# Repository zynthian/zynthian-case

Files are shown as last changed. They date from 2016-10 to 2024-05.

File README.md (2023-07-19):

# Zynthian Case

[Zynthian](http://zynthian.org) is an Open Synth Platform based in Raspberry Pi, Linux (Raspbian) and Free Software Synthesizers (mostly!).

Image of the official Zynthian Aluminium case

This repository contains the stuff related to case building: plots, schemes, renders, photos, CNC files, ...
You can find useful information about [building a Zynthian Box in the Wiki](http://wiki.zynthian.org/index.php/Zynthian_Box_Building)

Image of a Zynthian mini aluminum case
Image of a Zynthian rig 19inch case
Image of a Zynthian stronberg keyboard case
Image of a Zynthian vintage wood case
Image of a Zynthian Zevinchian case

For more examples of amazing zynthian cases, take a look to the [forum's "Success Cases" thread](https://discourse.zynthian.org/t/success-cases/41).

You can learn more about the Zynthian Project in any of our sites: 

+ [website](https://zynthian.org)
+ [wiki](https://wiki.zynthian.org)
+ [blog](https://blog.zynthian.org)
+ [forum](https://discourse.zynthian.org) => Join the conversation!!

You can buy official kits in the zynthian shop:

+ [shop](https://shop.zynthian.org)

# Credits
 + Ramón Besora ([Besmon](http://www.besmon.com)): Metal Case Design
 + Paul Alex Falduto: Initial 3D print design
 + Belén Fernández (Punt Multimedia de Sants): Revision 3D print design
 + Marc Soler: Cool rotulation ;-)
 + Susanna Sort: Laser-cutter wooden-case design
 + Many more ...

[Creative Commons Attribution-ShareAlike 4.0 International License](
http://creativecommons.org/licenses/by-sa/4.0/)
This work is licensed under a [Creative Commons Attribution-ShareAlike 4.0 International License](http://creativecommons.org/licenses/by-sa/4.0/)

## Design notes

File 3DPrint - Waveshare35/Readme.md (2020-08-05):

# 3D-printed case / RPi 4 / Waveshare 3.5"
The case design is created with the setup as described below, but I have also included the source file (Fusion 360) before all cutouts and joins, so it can easily be adapted to other setups.

My setup:
 + RPi 4 main board
 + HifiBerry DAC+ with phone jack
 + All-in-One controller / V2
 + Waveshare 3.5" touch screen

The case is designed so that each part prints separately, so you get the nice and smooth structure on all visible surfaces. I use the Prusa sintered build plate, looks fantastic.

The side parts are designed in such a way that they could be replaced by wooden parts instead. My goal is to create these in either cherry or oak at some point. But for now I printed them with Wood PLA to make it stand out a little.

Printing tip: For the bottom and top parts, avoid using the standard Rectilinear fill, it's much better to use a stiffer infill, like Cubic (in Prusa Slicer). This way there is a bigger chance that the edges will not detach from the buildplate during printing. In reality they probably will anyway, but usually to a smaller degree - it's difficult to print these large parts perfectly.

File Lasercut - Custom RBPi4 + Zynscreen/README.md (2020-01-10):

This fantastic case has been contributed by **Nicolai Demidenko**.
It's been designed for RBPi4 + Zynscreen, but include lot of extra customizations that improves the basic Kit v3 design.

Front view of the 3D-printed RBPi4+Zynscreen customized case

Back view of the 3D-printed RBPi4+Zynscreen customized case

This case for Zynthian involves quite a lot of additional work and is not a simple assembly. It requires lots of extra soldering and glueing parts.

Wires for MIDI sockets and LEDs have to be lenghtened. Additional parts required are 20W 5V 4A PSU available from aliexpress at less than 2 euros, 80mm 5V silent fan, 2 little On-Off switches for power and cooling fan, some screws, nuts (I used M3 and M2.5 where required) and 3mm high plastic supports for PCB's (12 altogether).

Inner and outer side panels have to be glued together, then three PCBs (RPi4, Audioinject Zero and MIDI controller) plus PSU and fan have to be mounted on the bottom panel, back and front panels have to be glued to the bottom one and altogether they have to be glued to the right side panel.

Left side panel uses 4 magnets (my magnets are 4.8mm diameter - but you can use other sizes, just modifying four holes). I provide .stl file as an example of the case receptacles for magnets (I use the same size magnets, they hold well); I glued them to the front, bottom and back sides (not to the top panel).

I ordered matte black acrylic for the face panel, but the seller sent me a glossy one;  as my design stands, I plan to use matt black for the face and outer side panels, and will replace glossy one with matte when my acrylic sheet arrives.

To prevent an electrical damage to the PSU when I use RPI power supply (when it is not connected to the mains - and connecting both at the same time is strictly NO if you don't want to fry your zynsinth) I installed a diode between PSU output and the circuits; 3A diode is enough, and 0.4V fall is easily compensated by a trimmer on the PSU.

Acrylic panels are all 3mm thick.

That's all...

Nicolai Demidenko

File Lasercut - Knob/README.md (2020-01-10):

# Laser-cut Zynthian-branded knobs

These Zynthian-branded knobs can be laser-cut and assembled to compliment a laser-cut Zynthian case. They are made from six discs of **3 mm material** stacked and glued together.

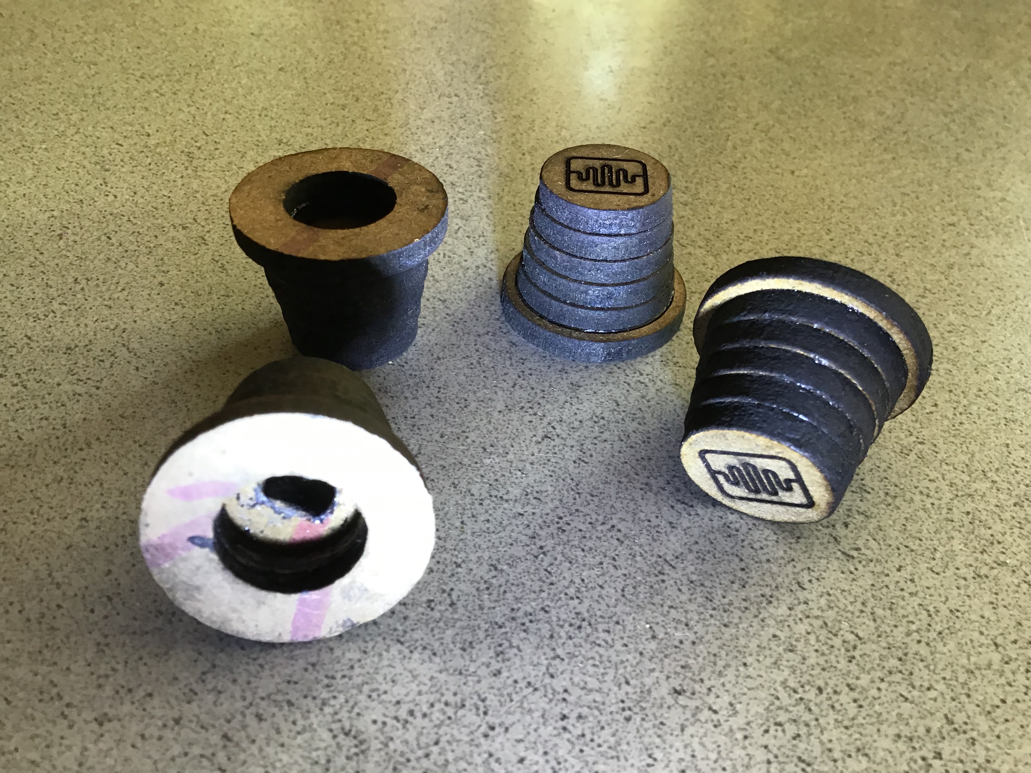
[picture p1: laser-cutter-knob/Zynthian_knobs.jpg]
Image of Zynthian knobs


## Laser cut files

Laser-cut files are provided in .dxf and .svg formats. The files are colour-coded and should be cut in the following order:

1. Blue - engrave
2. Red - inside cut
3. Black - outside cut

The knobs in the photos were made using [LaserWeb4](https://github.com/LaserWeb/LaserWeb4) and a K-40 laser cutter.

## Assembly

Glue the discs together on an encoder shaft to ensure proper aligment.

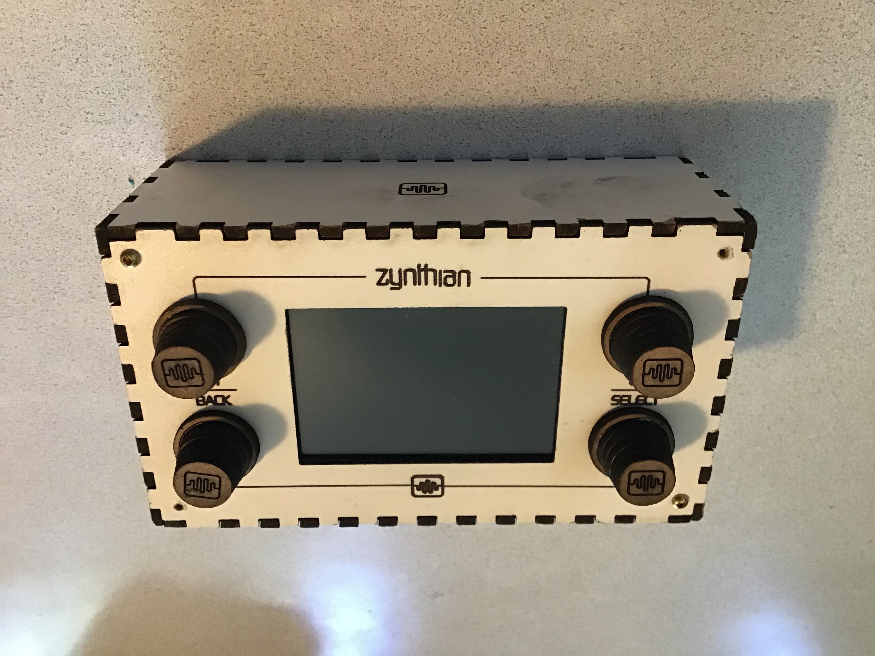
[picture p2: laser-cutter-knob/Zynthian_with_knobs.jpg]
Image of Zynthian with laser-cut knobs


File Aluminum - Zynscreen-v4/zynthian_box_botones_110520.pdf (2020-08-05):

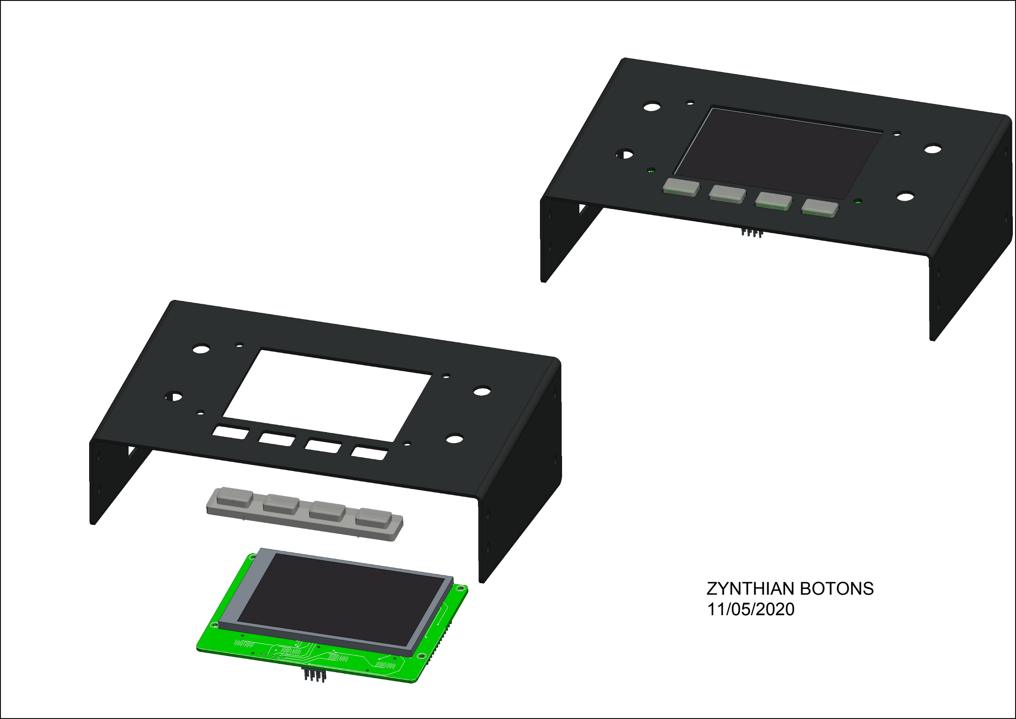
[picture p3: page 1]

ZYNTHIAN BOTONS
11/05/2020

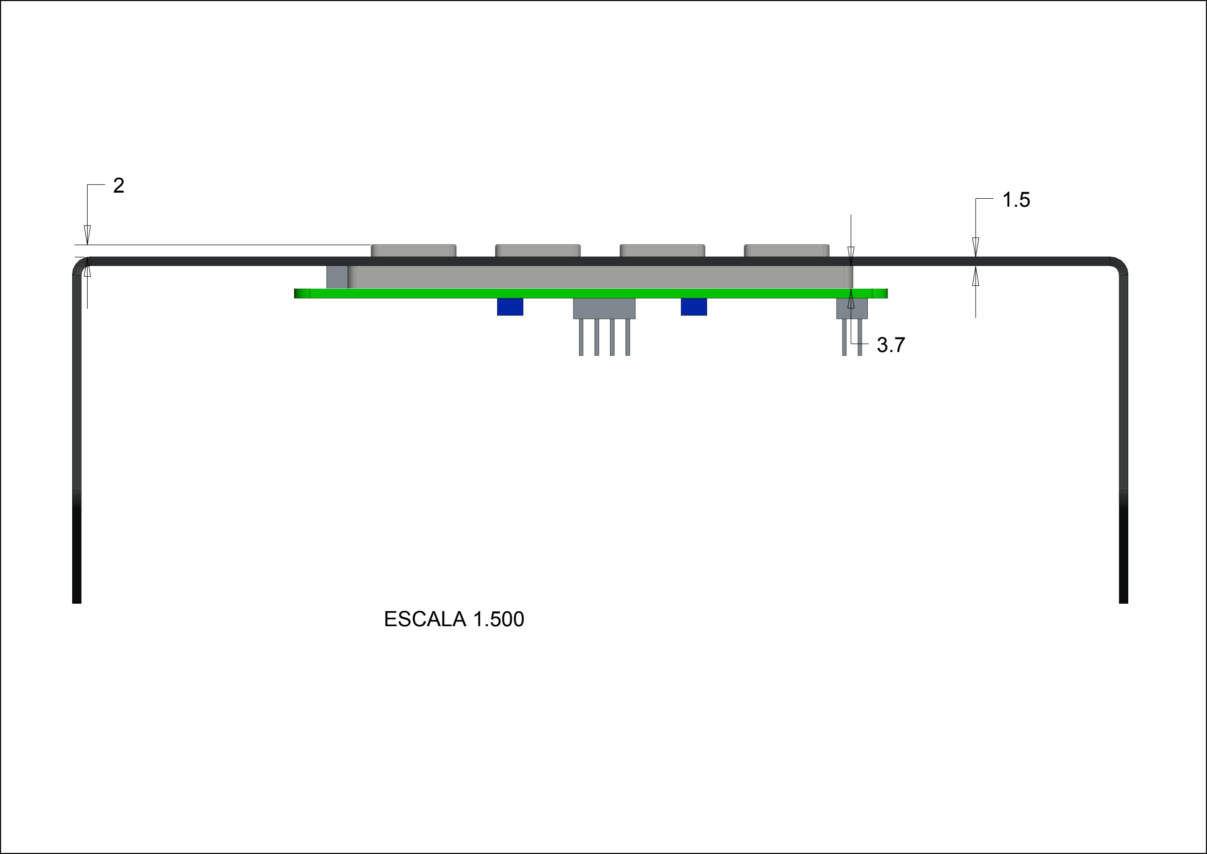
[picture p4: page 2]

3.7

2 | 1.5

ESCALA 1.500

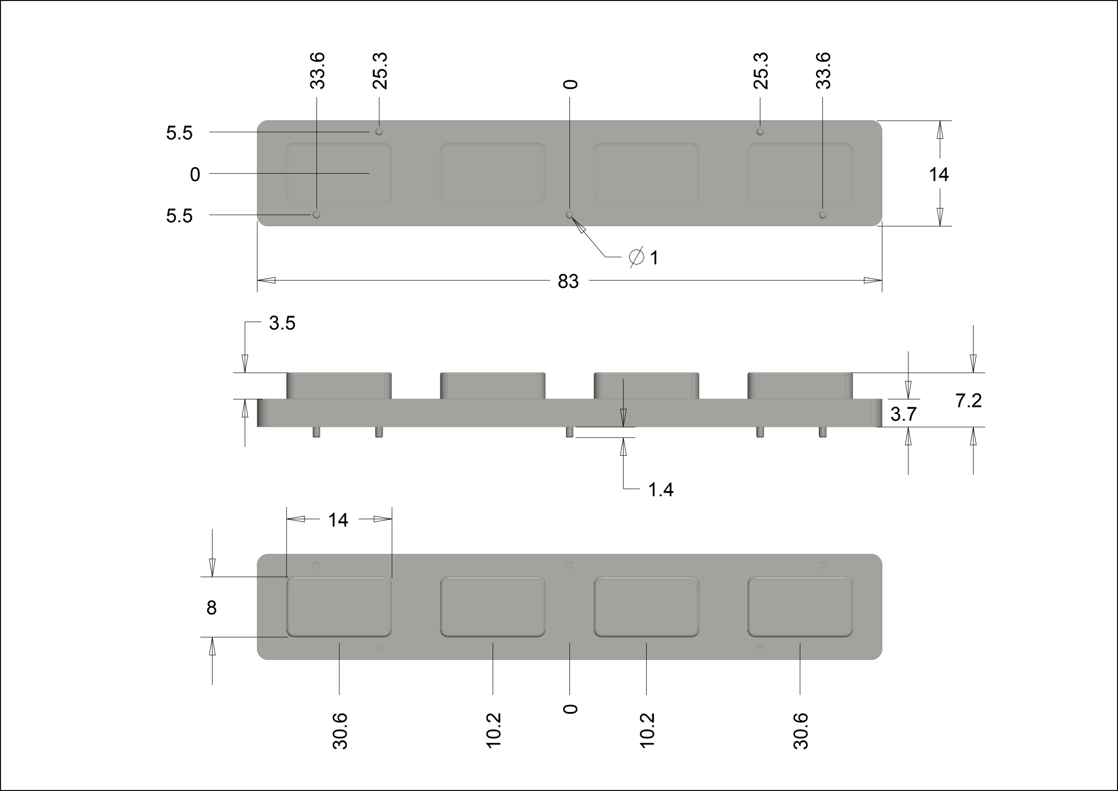
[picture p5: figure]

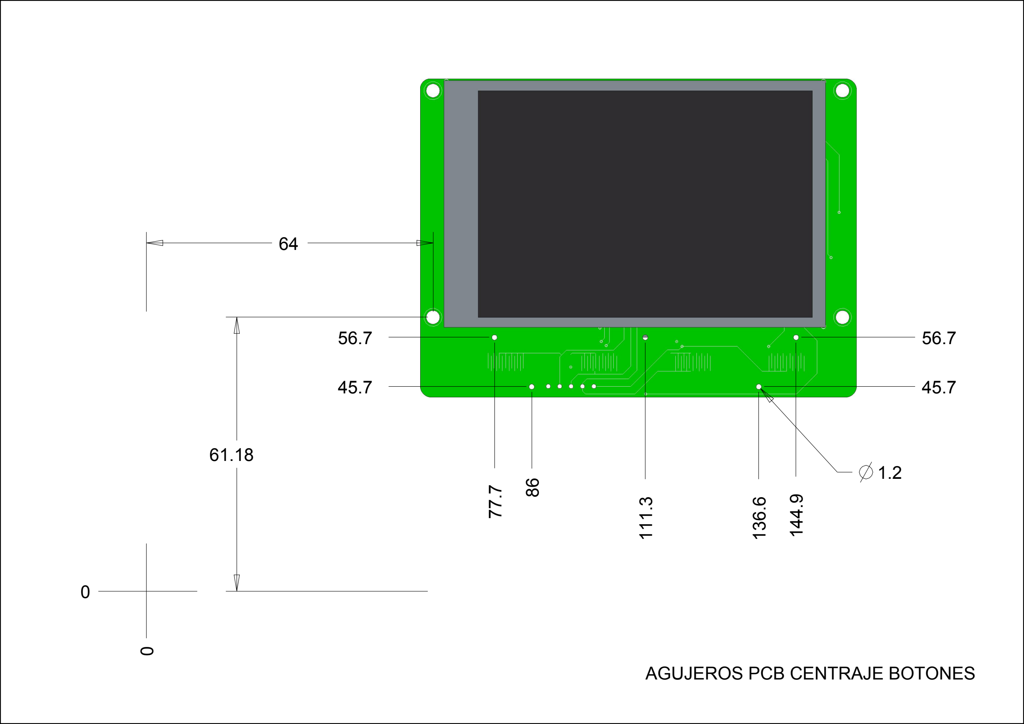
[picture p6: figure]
AGUJEROS PCB CENTRAJE BOTONES
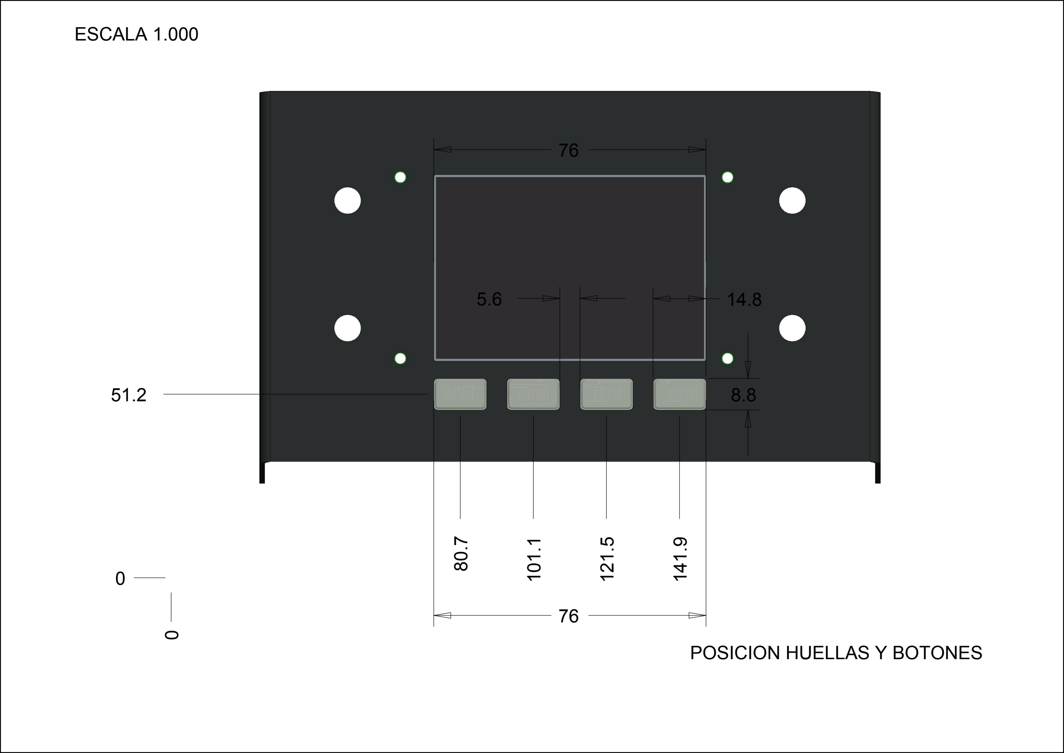
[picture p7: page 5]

80.7

0

101.1

121.5

141.9

51.2

0

5.6

76

76

14.8

8.8

POSICION HUELLAS Y BOTONES

ESCALA 1.000

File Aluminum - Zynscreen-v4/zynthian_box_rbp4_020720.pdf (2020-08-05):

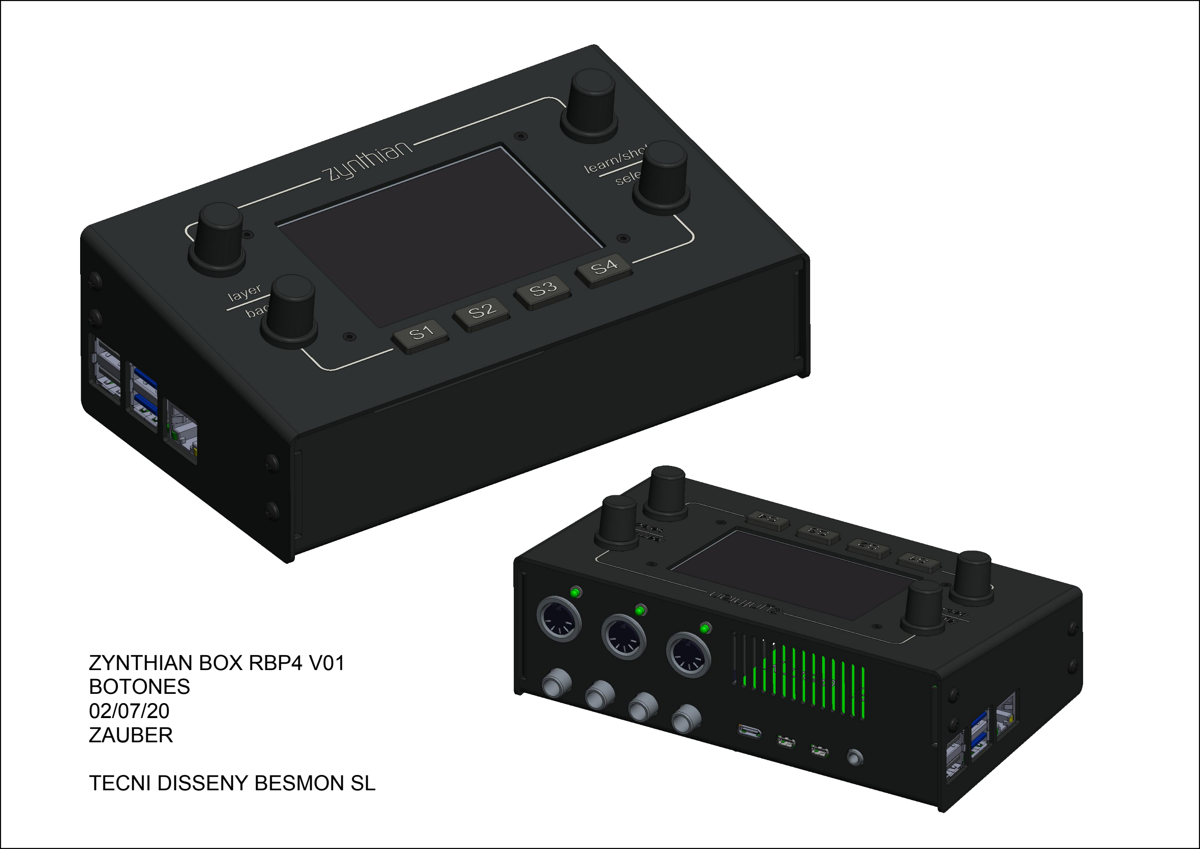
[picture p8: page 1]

ZYNTHIAN BOX RBP4 V01
BOTONES
02/07/20
ZAUBER
TECNI DISSENY BESMON SL

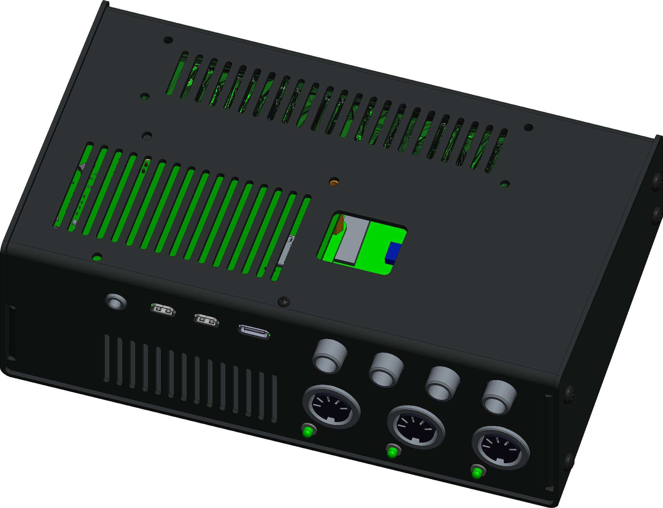
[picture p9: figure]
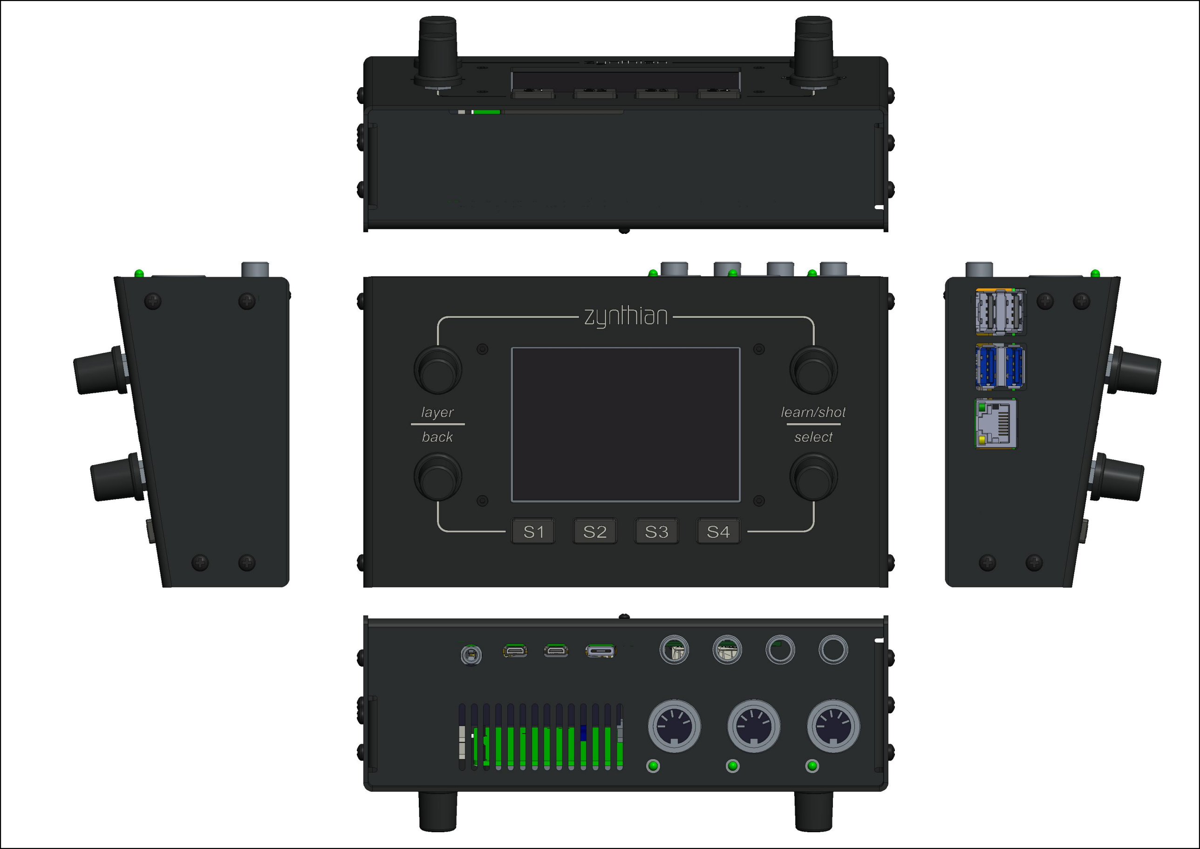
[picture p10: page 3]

ESCALA 1.000

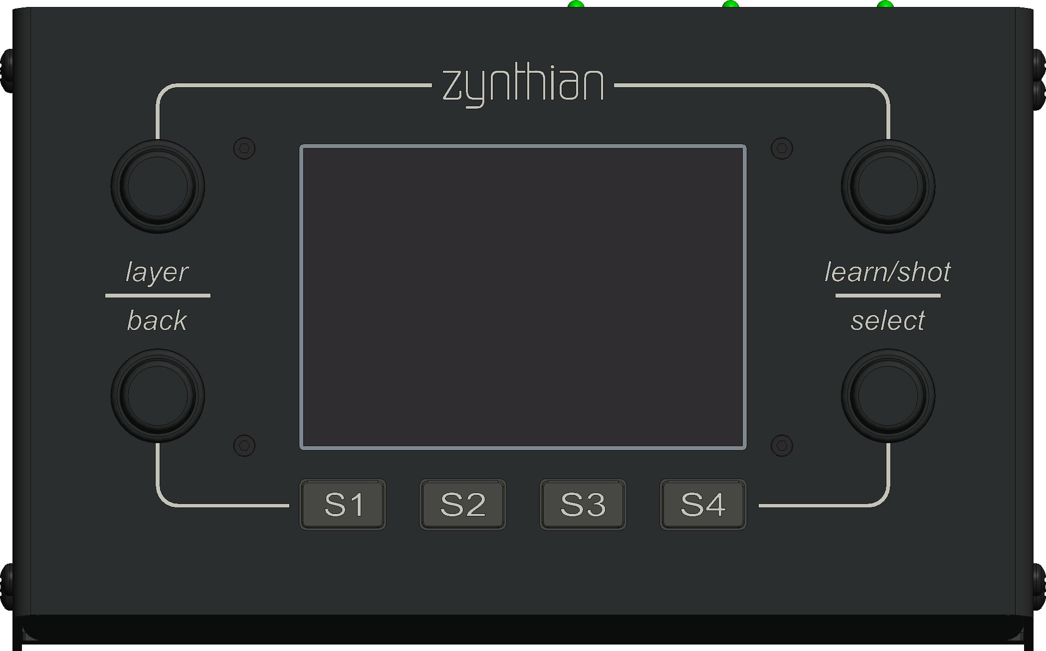
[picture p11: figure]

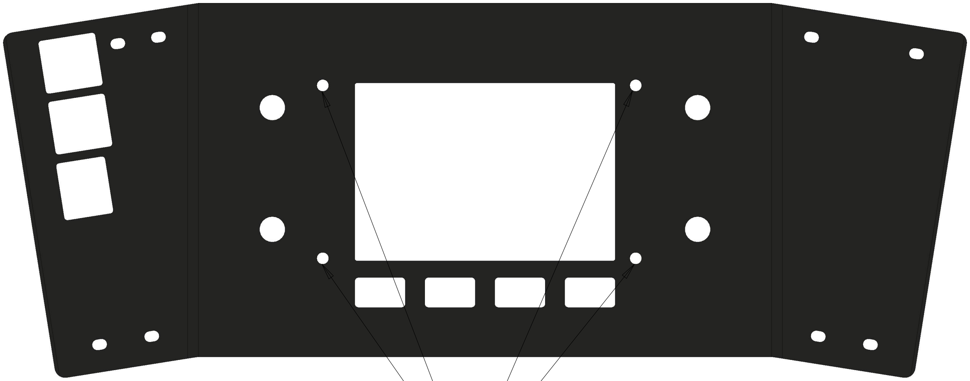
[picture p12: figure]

ESCALA 1.000

AVELLANAR
SEGONS CARGOL
MOSTRA

170

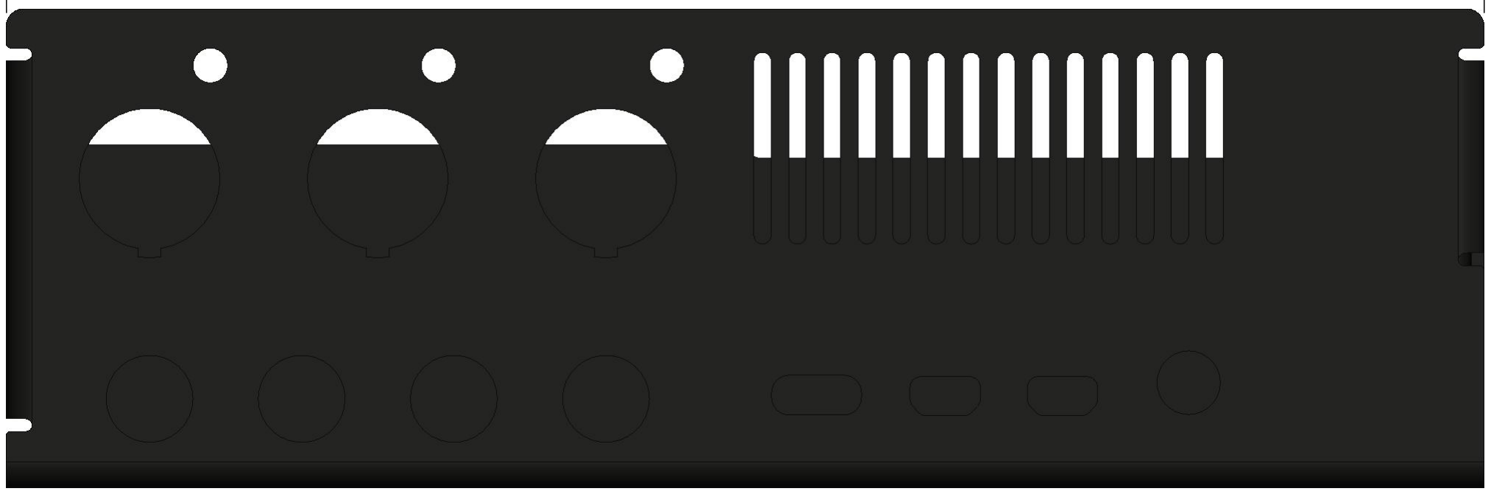
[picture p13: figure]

BASE ZYNTHIAN SERIGRAFIA

ESCALA 1.000

173.2

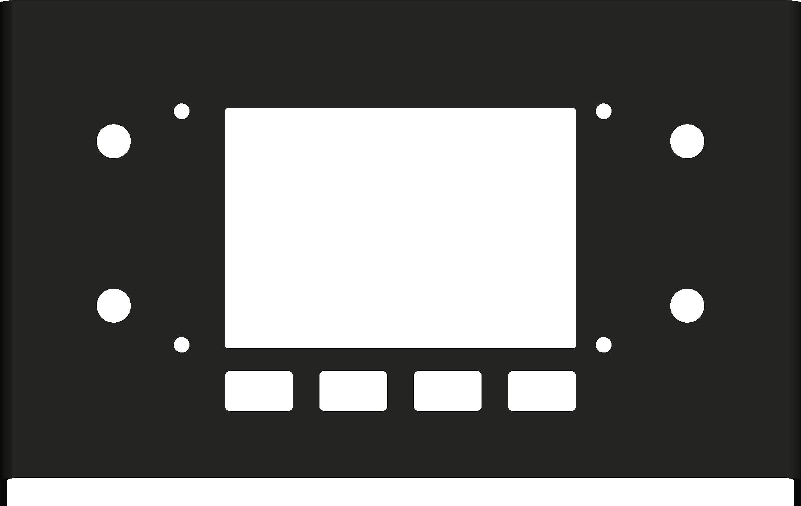
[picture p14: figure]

TAPA ZINTHIAN SERIGRAFIA | ESCALA 1.000

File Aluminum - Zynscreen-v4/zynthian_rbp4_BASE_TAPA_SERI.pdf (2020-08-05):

170

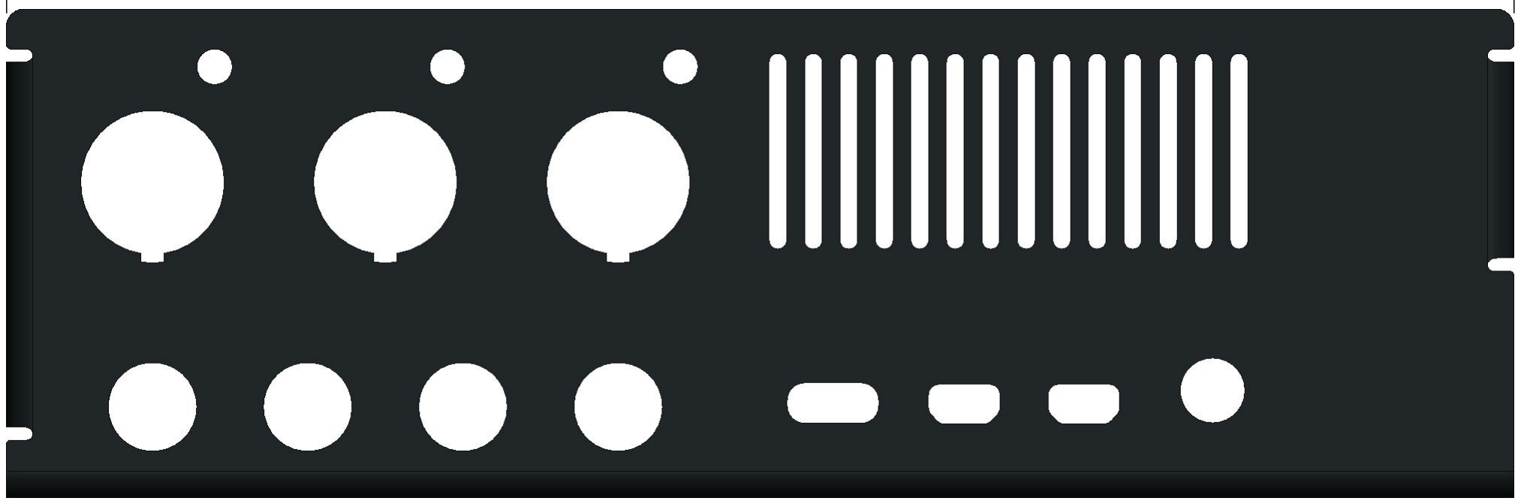
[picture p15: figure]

BASE ZYNTHIAN SERIGRAFIA

ESCALA 1.000

173.2


TAPA ZINTHIAN SERIGRAFIA | ESCALA 1.000

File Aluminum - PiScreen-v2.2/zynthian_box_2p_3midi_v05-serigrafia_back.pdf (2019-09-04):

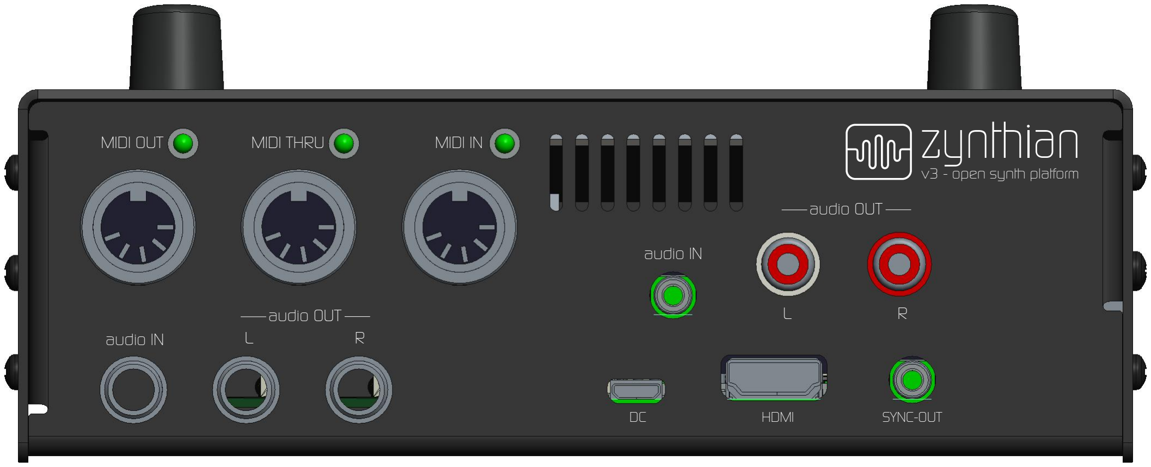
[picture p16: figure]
MIDI OUT; HDMI; SYNC-OUT; MIDI THRU; MIDI IN; audio IN; audio OUT; v3 - open synth platform

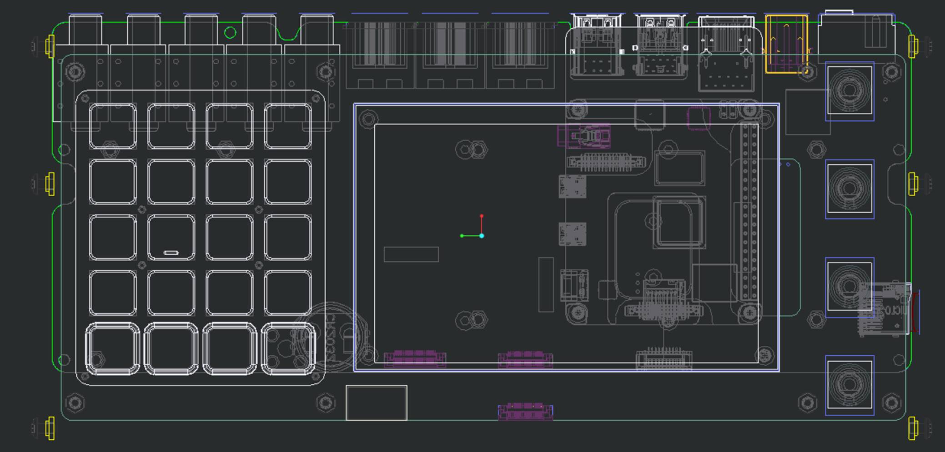
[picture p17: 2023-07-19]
V5 - Aluminum/img/V5_electronics_01.jpg

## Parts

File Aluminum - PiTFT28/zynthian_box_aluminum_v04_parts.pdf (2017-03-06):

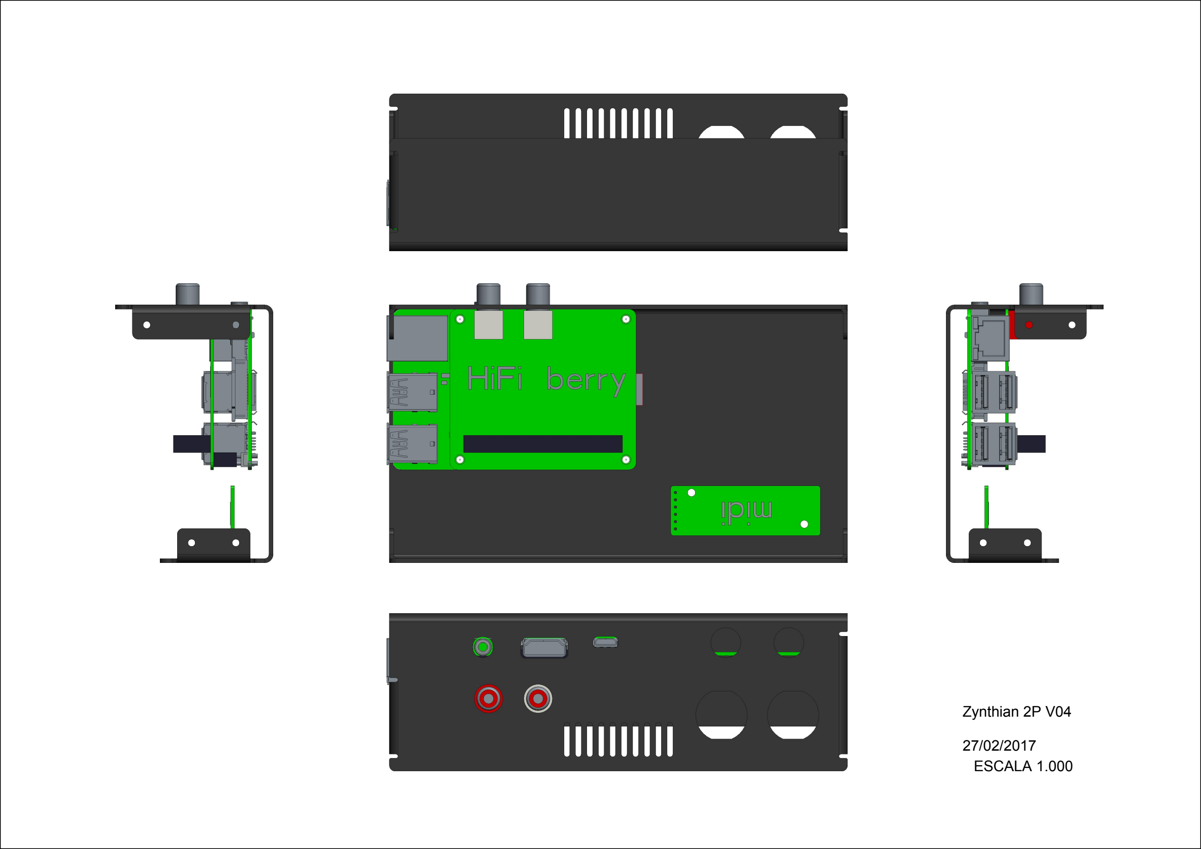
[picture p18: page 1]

Zynthian 2P V04
27/02/2017
ESCALA 1.000

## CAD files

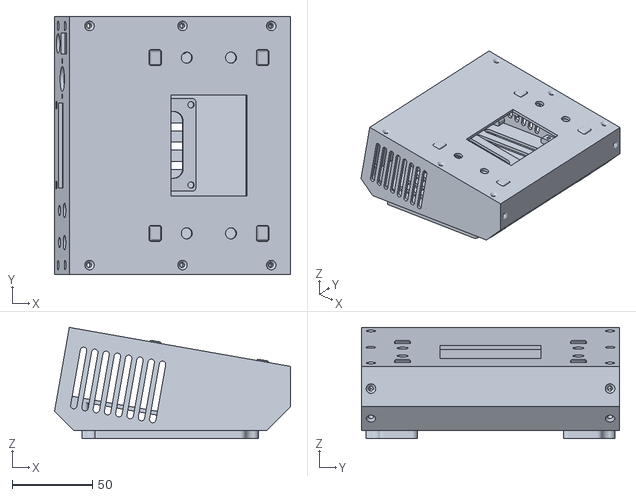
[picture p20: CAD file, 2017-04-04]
3D Print - Big/FullAssembly.stl
147.1 x 160.8 x 69.3

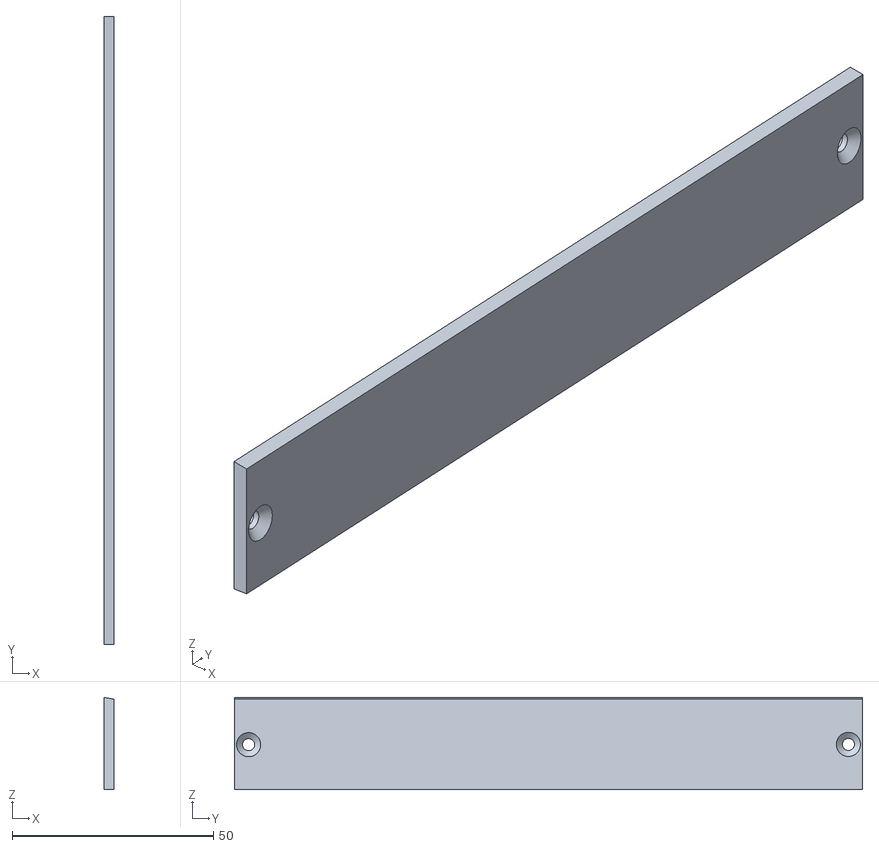
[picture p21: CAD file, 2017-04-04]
3D Print - Big/Top Front.stl
2.50 x 156.0 x 22.9

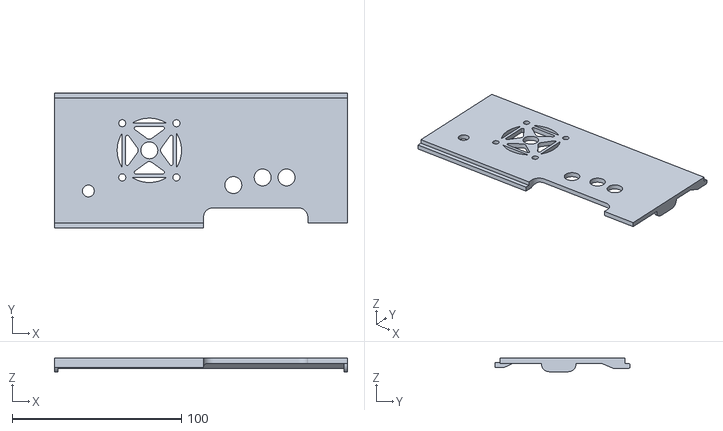
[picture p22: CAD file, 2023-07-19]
3D Print - Lafranco/Retro.stl
173.0 x 80.0 x 8.00

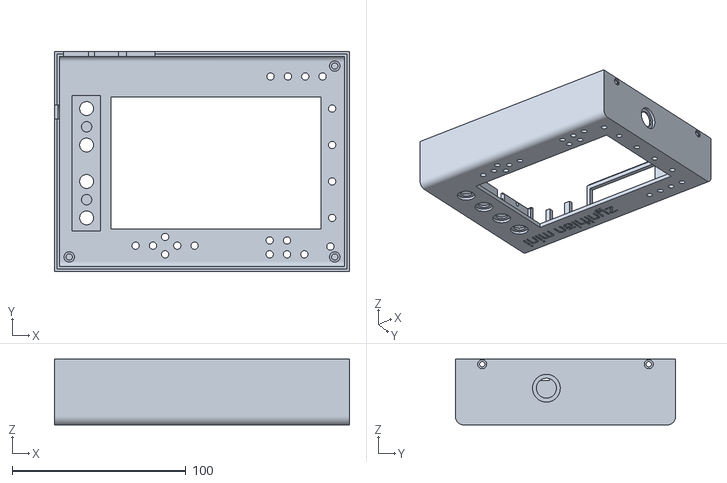
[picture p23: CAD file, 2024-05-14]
3D Print - Mini V2/top.stl
170.0 x 127.0 x 38.0

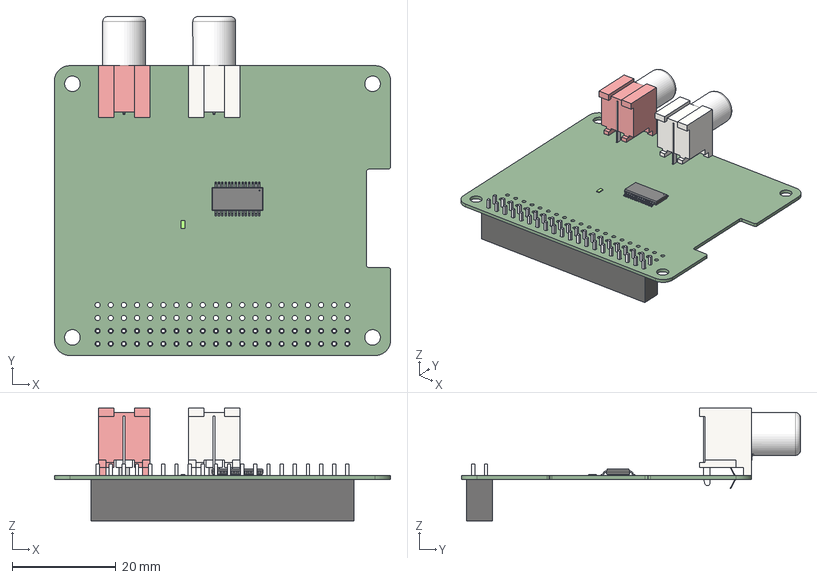
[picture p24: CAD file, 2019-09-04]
3D Print - Parts models/hifiberry-dac-1.snapshot.1/HifiberryDAC+.step
65.0 x 65.5 x 21.8 mm
LED
Pin header
IC v1
RCA rouge
RCA blanche

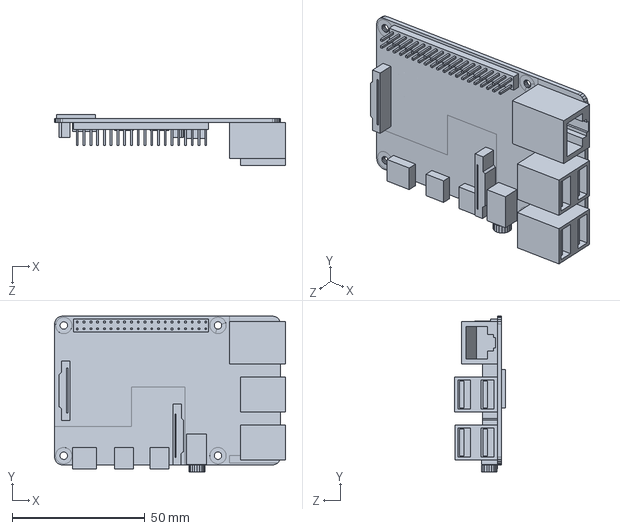
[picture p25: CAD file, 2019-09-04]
3D Print - Parts models/raspberry-pi-4-b-1.snapshot.4/Raspberry Pi 4 B.STEP
86.9 x 58.6 x 19.0 mm

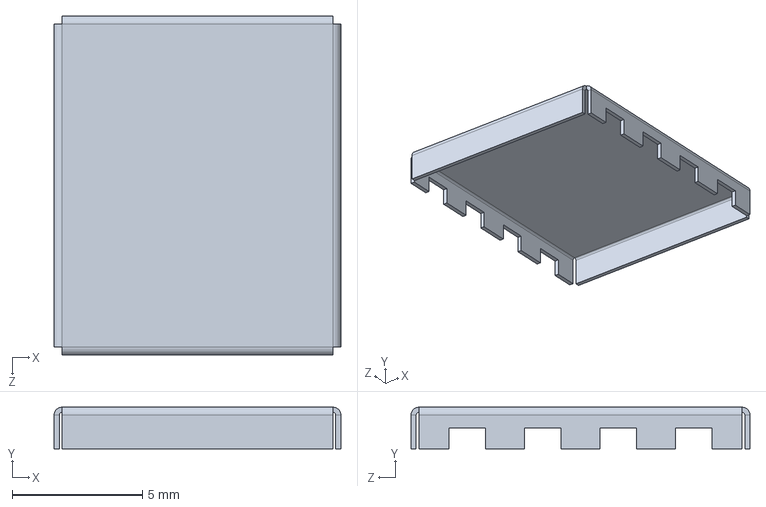
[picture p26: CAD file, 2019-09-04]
3D Print - Parts models/raspberry-pi-4-model-b-1.snapshot.3/Cypress CYW43455 Wireless Module Cover, RPi4ModelB.SLDPRT
11.0 x 1.60 x 13.0 mm

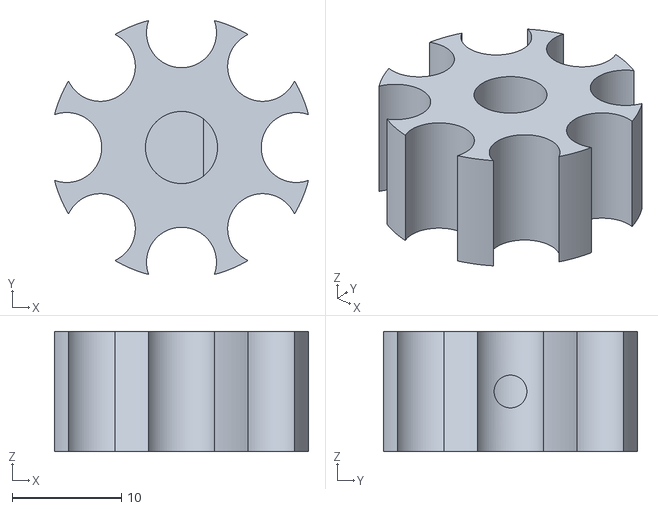
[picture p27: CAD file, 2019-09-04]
3D Print - PiScreen2 + 3xMIDI/encoderknob_3mm.stl
23.2 x 23.2 x 11.0

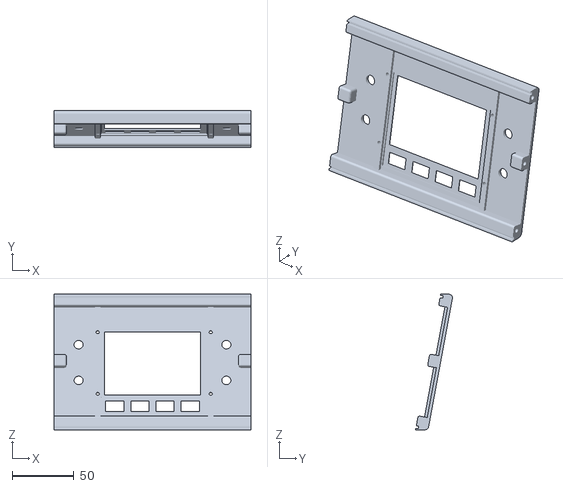
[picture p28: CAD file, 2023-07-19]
3D Print - Zynscreen 1.5 (V4)/STL files/Zynthian case top v4.stl
160.0 x 30.0 x 110.2

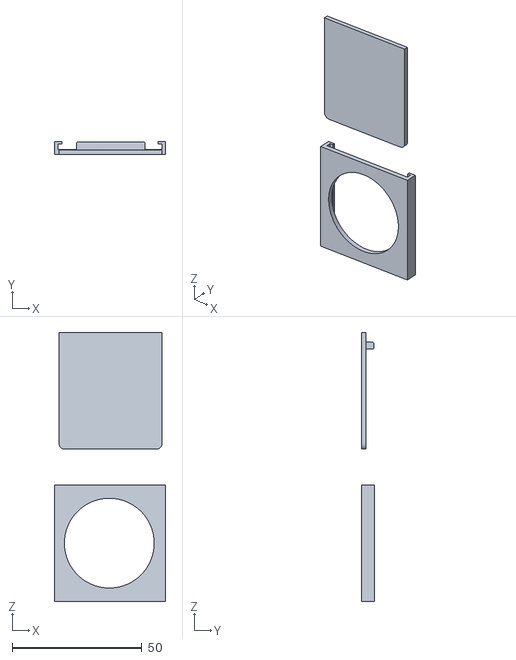
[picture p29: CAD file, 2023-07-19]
3D Print - Zynthian 4.3/File stl Case Zynthian/Copri SD.stl
43.0 x 5.00 x 103.7

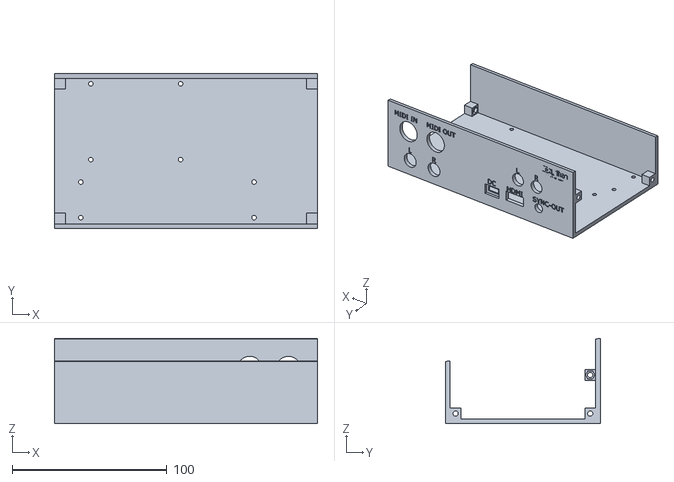
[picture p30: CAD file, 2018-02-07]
3DPrint - PiScreen2/bottom-box.stl
170.0 x 100.1 x 55.1

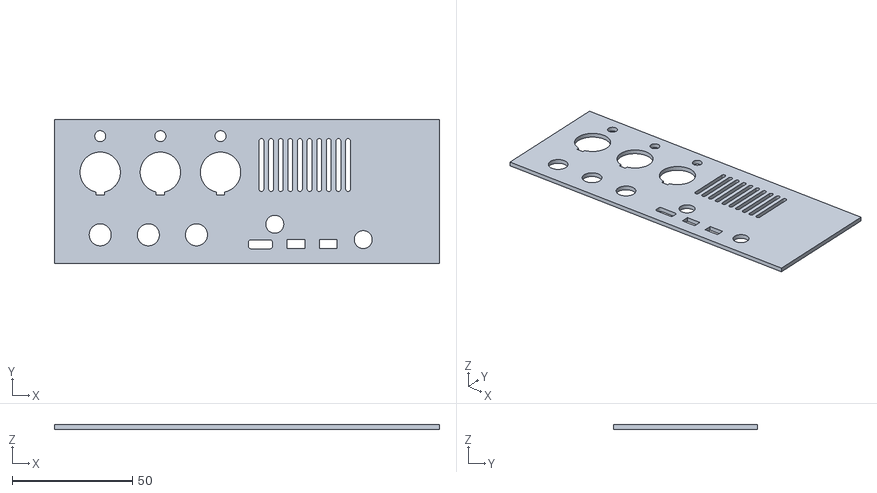
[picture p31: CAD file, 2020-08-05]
3DPrint - Waveshare35/Zynthian_Back_v1.stl
160.0 x 60.0 x 2.00

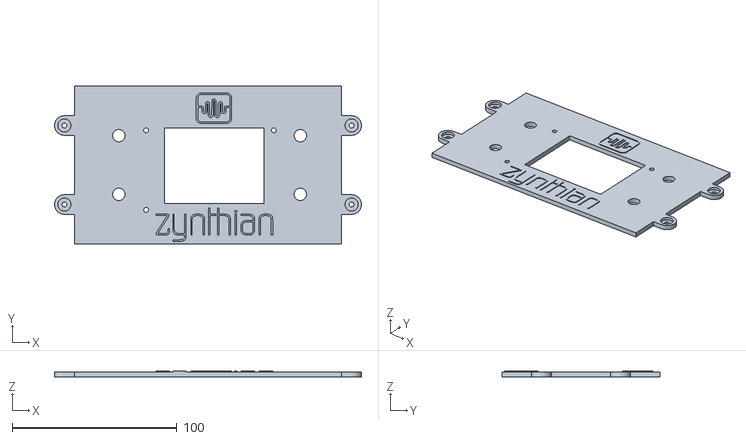
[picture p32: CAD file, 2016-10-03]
3DPrint/zyn_box_up.stl
186.3 x 95.9 x 3.48

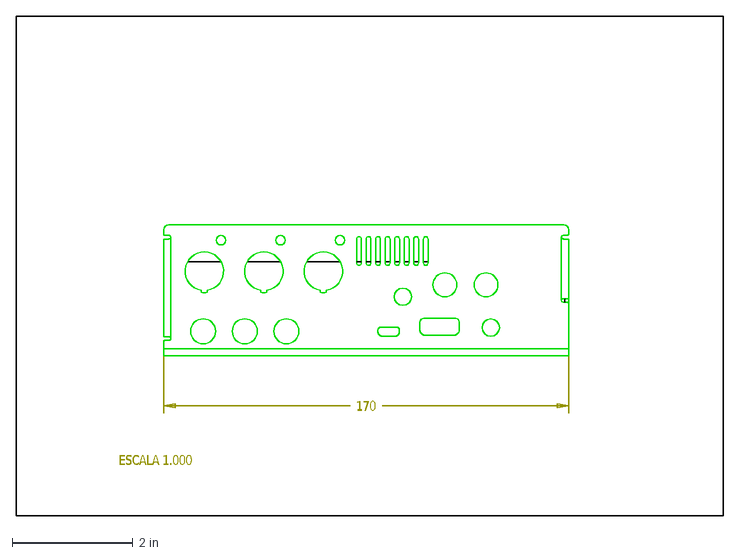
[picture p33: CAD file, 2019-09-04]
Aluminum - PiScreen-v2.2/zynthian_box_2p_v06_mjack_5.2.dxf
170
ESCALA 1.000

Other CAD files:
Aluminum - Zynscreen-v4/rubber_buttons/ZYNT3.IGS
laser-cutter-audioinjector/slopes/zynthian_box_lasser_cutter_all.dxf
laser-cutter-audioinjector/zynthian_box_lasser_cutter_all.dxf
3D Print - Big/Bottom Back.stl
3D Print - Big/Bottom Front.stl
3D Print - Big/Button.stl
3D Print - Big/Foot L.stl
3D Print - Big/Foot R.stl
3D Print - Big/Knob.stl
3D Print - Big/Left Side.stl
3D Print - Big/Right Side.stl
3D Print - Big/Rpi SUPPORT.stl
3D Print - Big/Top Back.stl
3D Print - Big/Top Cover.stl
3D Print - Big/Underside.stl
3D Print - Lafranco/Fianco DX.stl
3D Print - Lafranco/Fianco SX.stl
3D Print - Lafranco/Fondo.stl
3D Print - Lafranco/Frontale 4.3.stl
3D Print - Lafranco/Fronte.stl
3D Print - Lafranco/mascherina 4.3.stl
3D Print - Mini V2/Raspberry_Pi_4_B.STEP
3D Print - Mini V2/bottom.stl
3D Print - Mini V2/leg.stl
3D Print - Mini V2/orca-slicer-project-01.3mf
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

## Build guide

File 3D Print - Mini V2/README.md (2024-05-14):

This repo include design details for 3d printable Case for Zynthian MINI V2 synthisizer. 

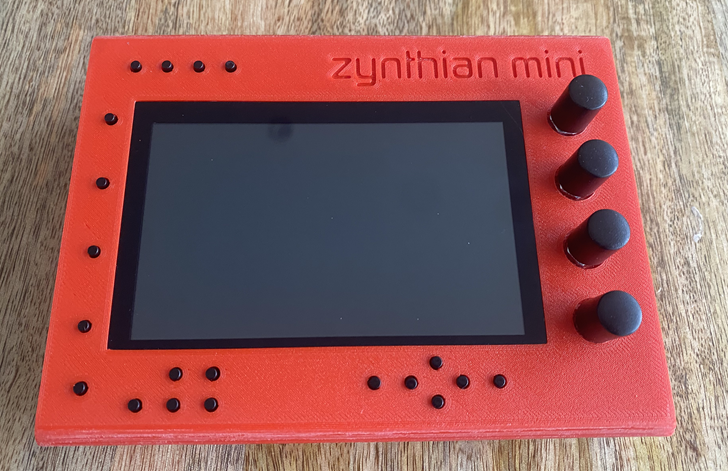
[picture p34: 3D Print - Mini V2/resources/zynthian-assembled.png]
Zynthian Mini V2


Zynthian Case is designed usign FreeCAD or its equivalent Ondsel software. 

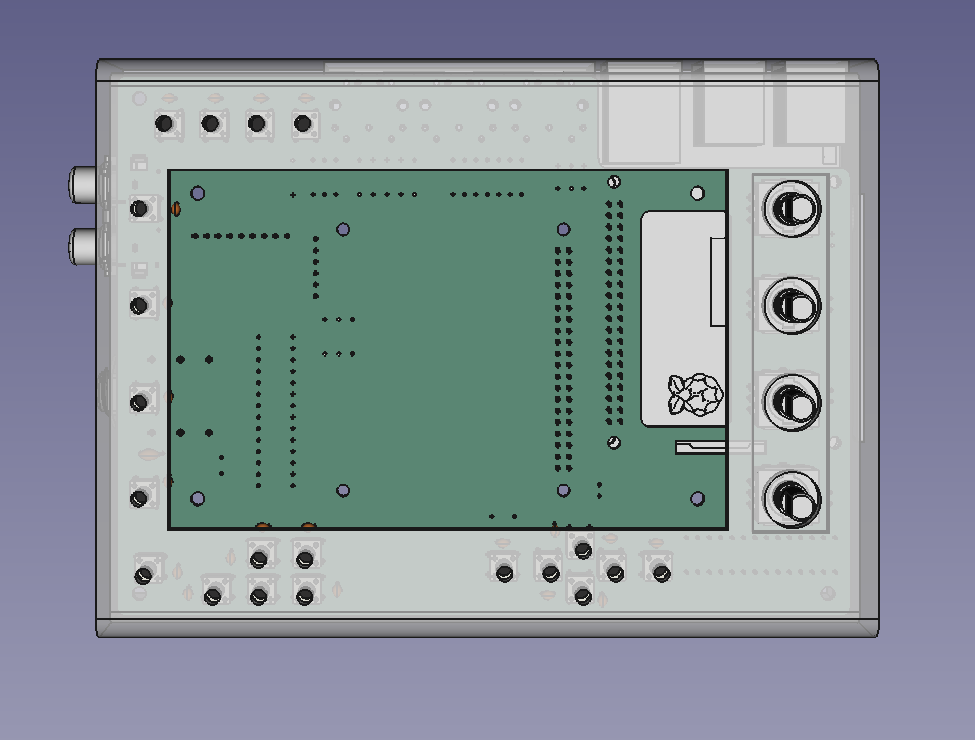
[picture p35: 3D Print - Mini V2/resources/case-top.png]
Zynthian Mini V2 CAD drawing


For more infromation about what zynthian mini V2 is and how to assemble go to [wiki](https://github.com/sstojos/zynthian-mini/wiki) page. 

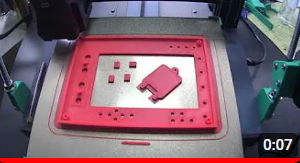
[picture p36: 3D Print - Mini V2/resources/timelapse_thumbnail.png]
Zynthian Mini V2 3d printing timelapse
[)](https://youtu.be/5RSKHbG7Gxg)

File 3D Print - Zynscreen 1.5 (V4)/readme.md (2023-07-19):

#Zynthian V4 case for Raspberry Pi4 + Zynscreen 1.5 with buttons and HiFiBerry DAC+ADC board with audio outs

This folder contains theSTL and Fusion 360 files of the top and back plates only. I've also added the bottom, front and side panels, which were originally
designed by user LeifA on Thingiverse
https://www.thingiverse.com/thing:4344990

Here's the list of hardware this case is compatible with:

- Zynscreen 1.5 with buttons
- Zynaptic module
- Raspberry Pi4
- HiFiBerry DAC+ADC
- 5 Pin 180 Deg DIN Panel Mounting Socket from Deltron (MIDI outs)
- 6.35mm (1/4") Enclosed Stereo Panel Jack Socket (Audio In/Out)
- Zynthian or any other encoders

All the parts are interchangeable with the original design of LeifA

This design is also available on Thingiverse:
https://www.thingiverse.com/thing:4749492

Have fun!

Venray, The Netherlands
5/2/2021

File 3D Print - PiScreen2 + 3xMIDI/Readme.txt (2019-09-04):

This box is a modification of the 3D printed case for Zynthian V2. No serigraphy, only the Zynthian logo.
It has 3 Midi connectors and a stereo 6,35 jack for the auxiliary output.
The union of the two parts of the case is made by insert nuts (4mm outside diameter). You can push them with the soldering iron.
There are two versions of the encoder knobs: 4mm (for insert nuts) and 3mm holes . In both cases use ad M3 screw without head for a perfect fit.

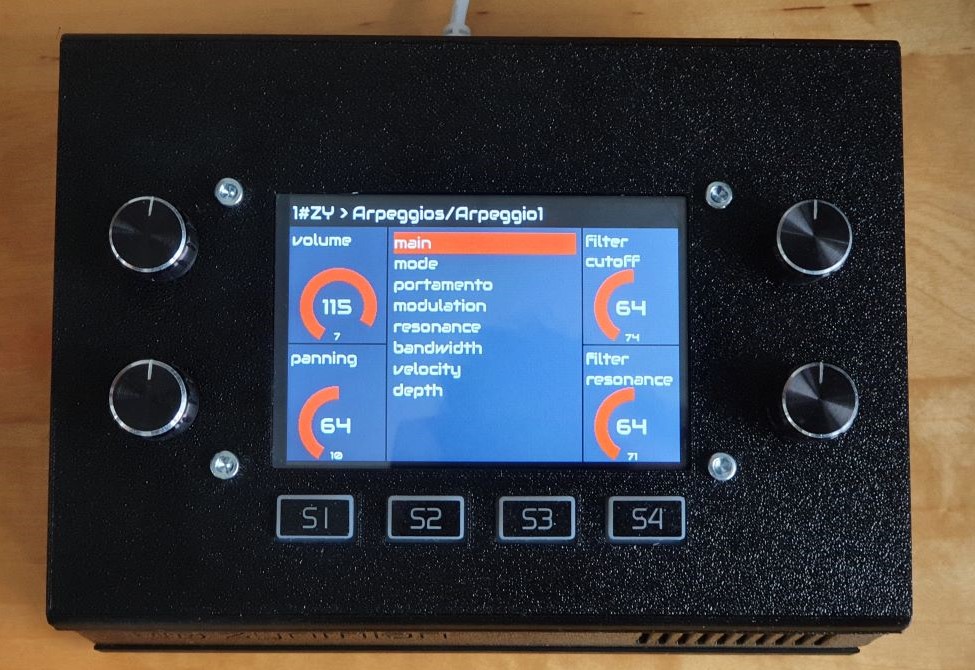
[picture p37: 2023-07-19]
3D Print - Zynscreen 1.5 (V4)/Pictures/top view.jpg

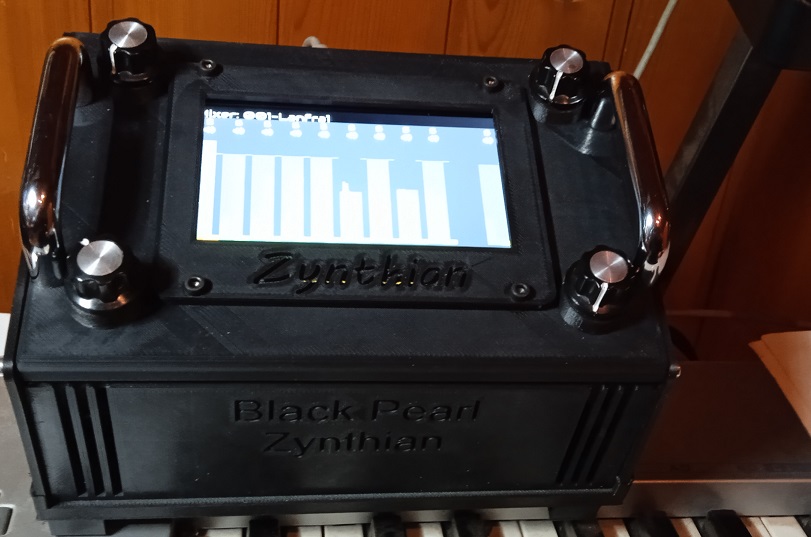
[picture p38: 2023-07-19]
3D Print - Zynthian 4.3/Images/1673954720845.jpg

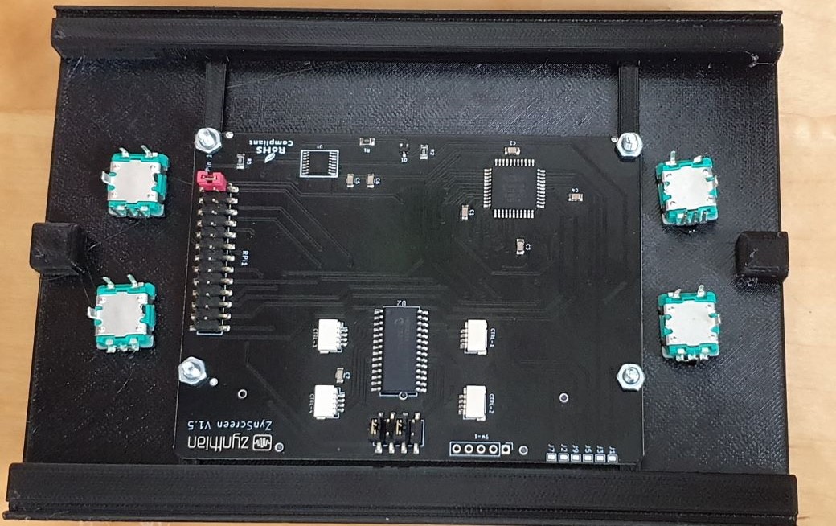
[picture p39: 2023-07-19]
3D Print - Zynscreen 1.5 (V4)/Pictures/top-inside.jpg

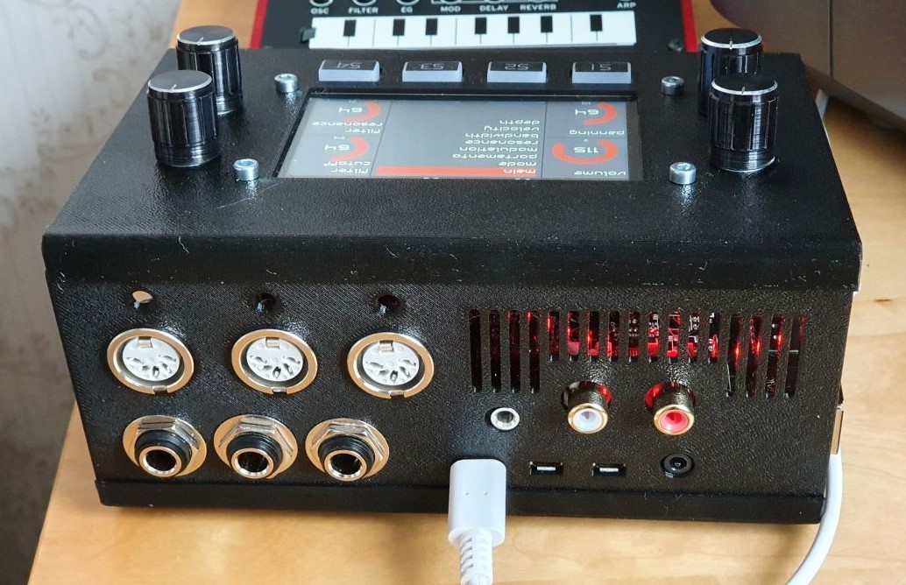
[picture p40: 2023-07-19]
3D Print - Zynscreen 1.5 (V4)/Pictures/back.jpg

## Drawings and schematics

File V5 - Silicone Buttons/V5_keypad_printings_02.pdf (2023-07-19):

ZS3

## MIX

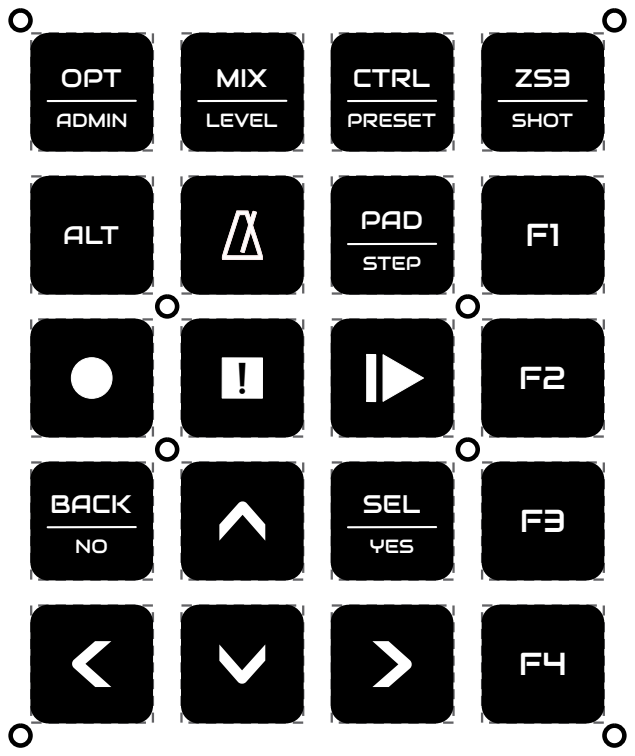
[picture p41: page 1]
PAD; SEL; YES; SHOT; STEP; LEVEL; BACK; ALT; OPT; ADMIN; CTRL; PRESET

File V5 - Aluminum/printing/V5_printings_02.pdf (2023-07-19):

V5

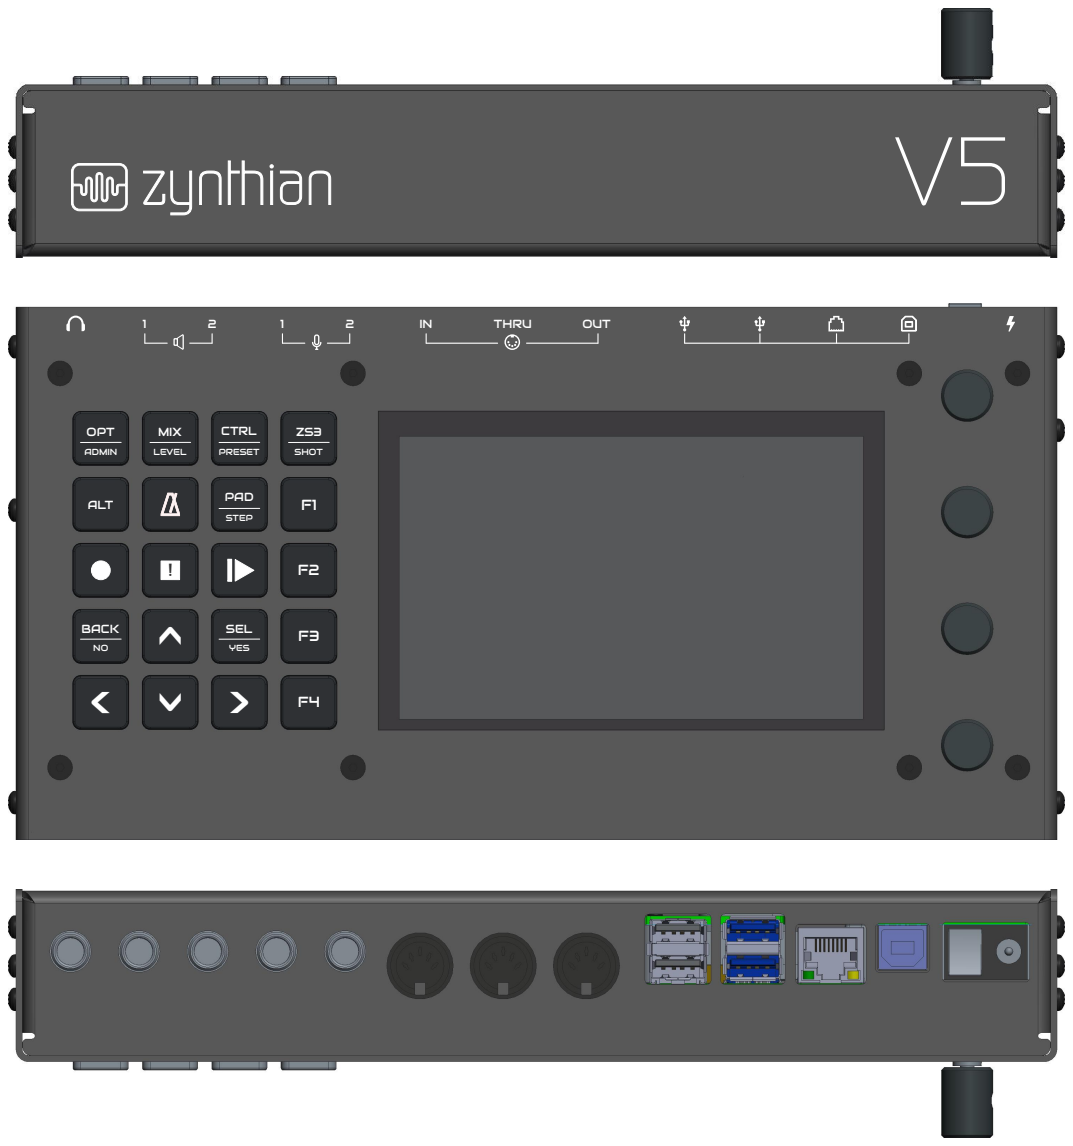
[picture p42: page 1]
THRU; OUT; CTRL; SEL; YES; PRESET; MIX; LEVEL; BACK; ALT; OPT; ADMIN; SHOT; PAD; STEP

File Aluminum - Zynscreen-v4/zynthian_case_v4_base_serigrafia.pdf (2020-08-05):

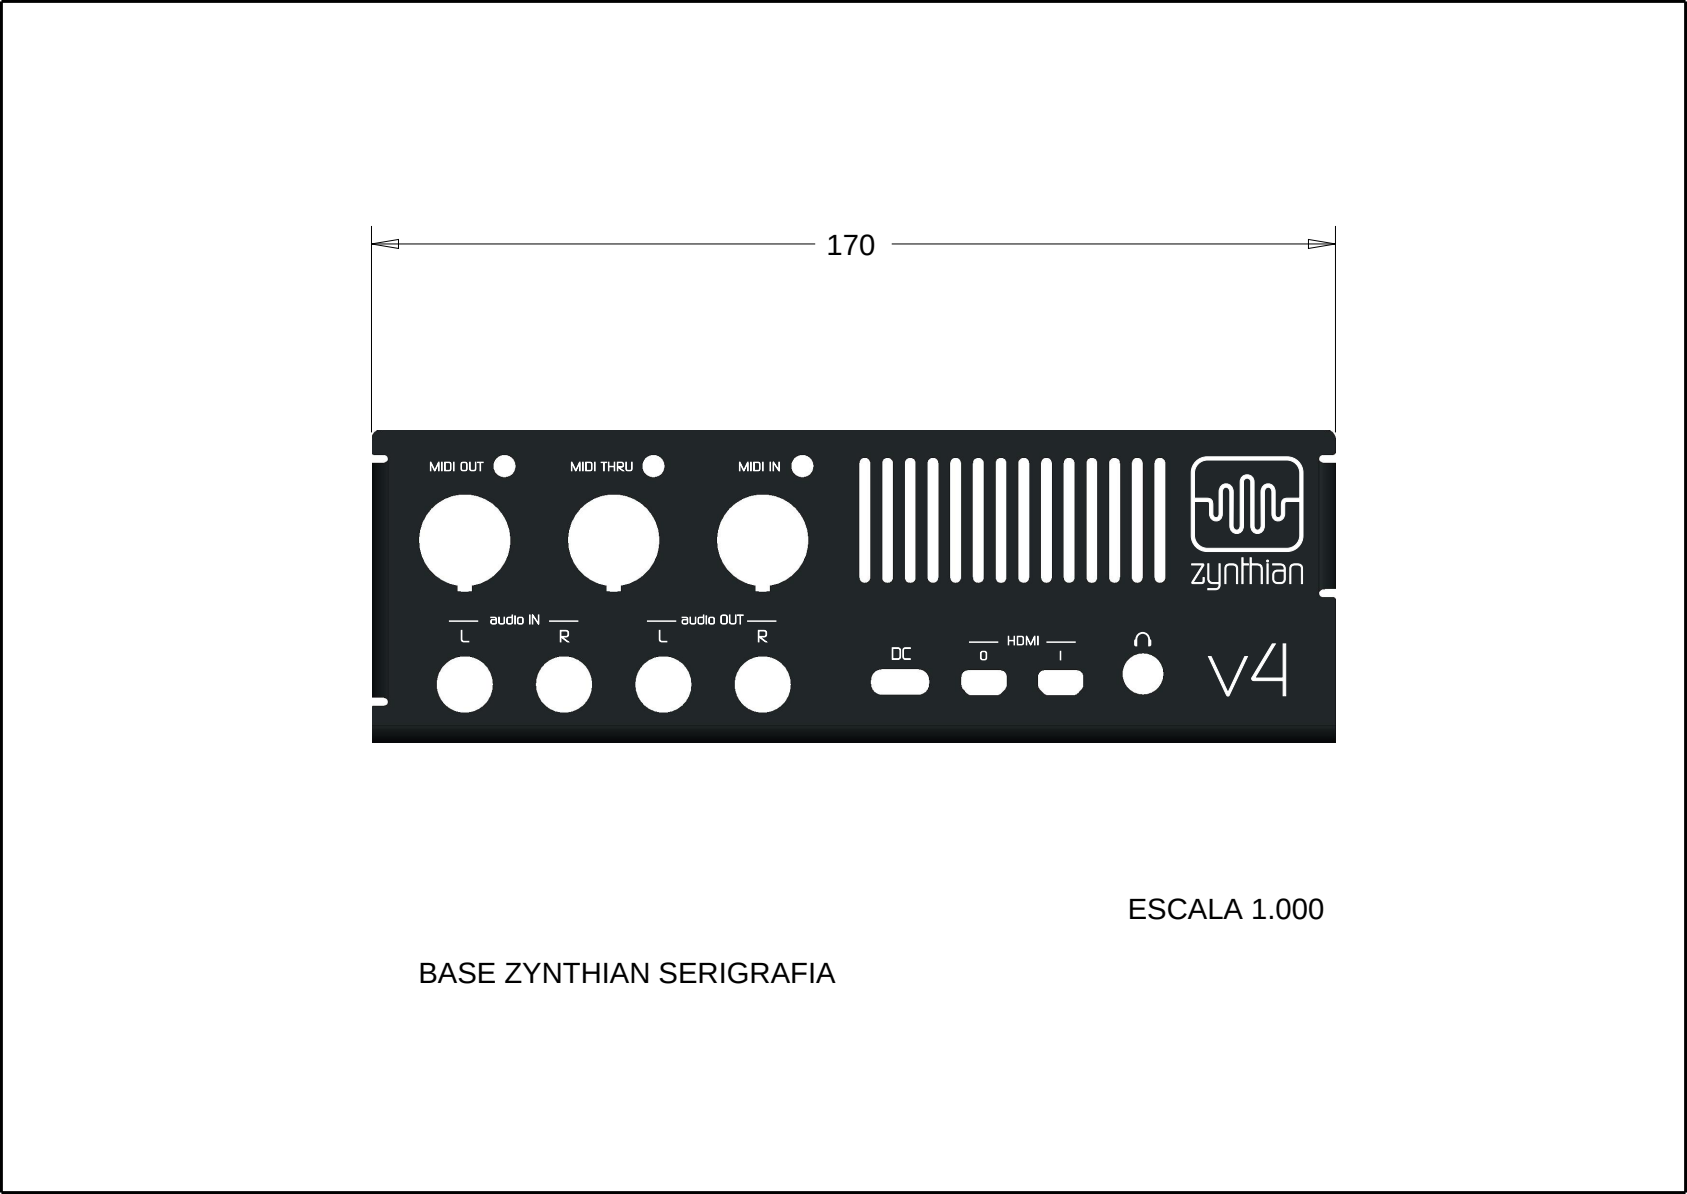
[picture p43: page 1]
ESCALA 1.000; MIDI; OUT; THRU; audio; audio OUT; HDMI

BASE ZYNTHIAN SERIGRAFIA

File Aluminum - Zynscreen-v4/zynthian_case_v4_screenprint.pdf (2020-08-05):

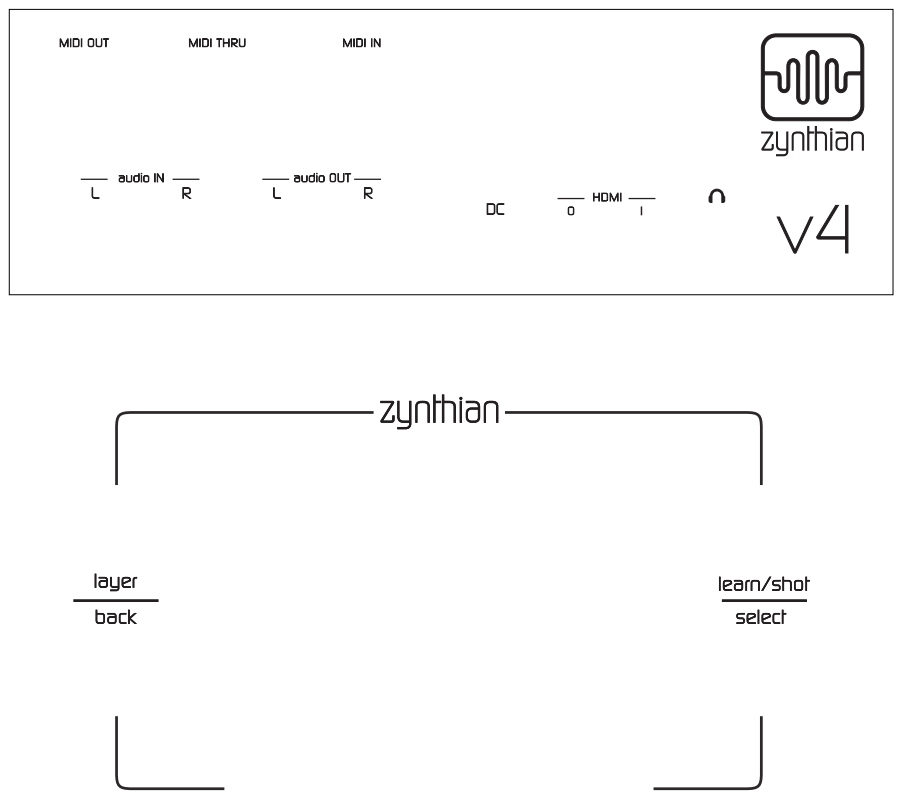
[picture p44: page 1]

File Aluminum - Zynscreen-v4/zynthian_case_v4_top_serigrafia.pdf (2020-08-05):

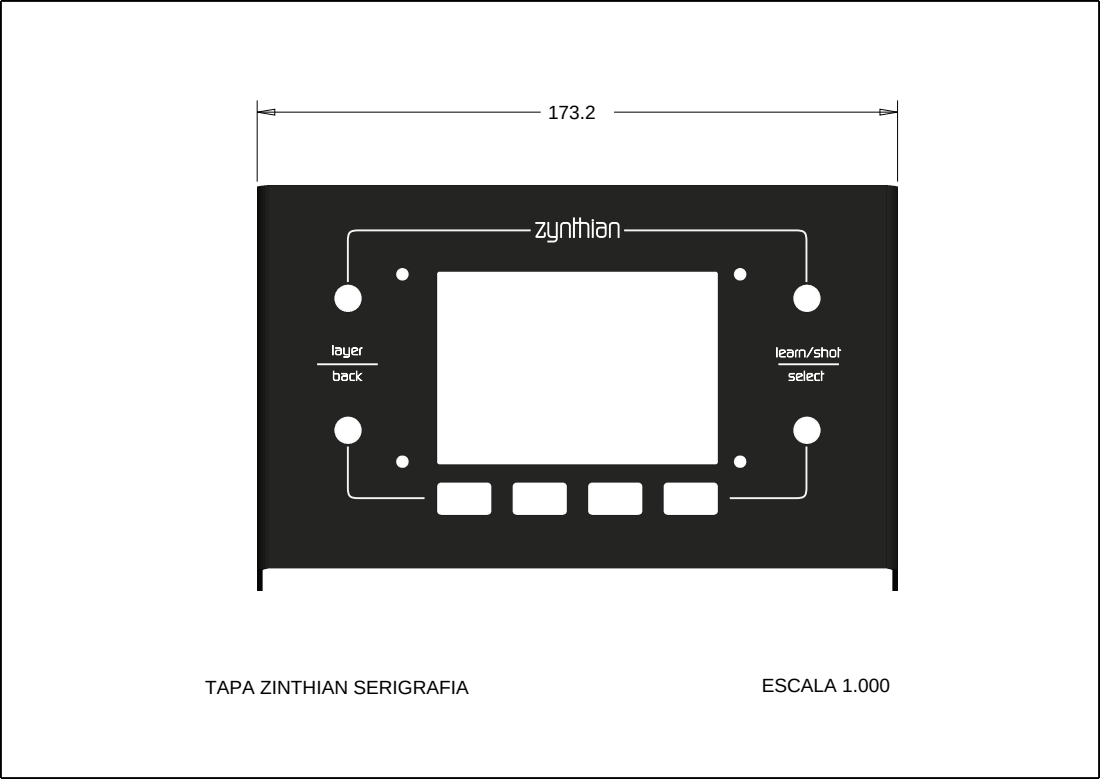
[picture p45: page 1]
TAPA ZINTHIAN SERIGRAFIA; ESCALA 1.000; layer; back; learn/shot; select

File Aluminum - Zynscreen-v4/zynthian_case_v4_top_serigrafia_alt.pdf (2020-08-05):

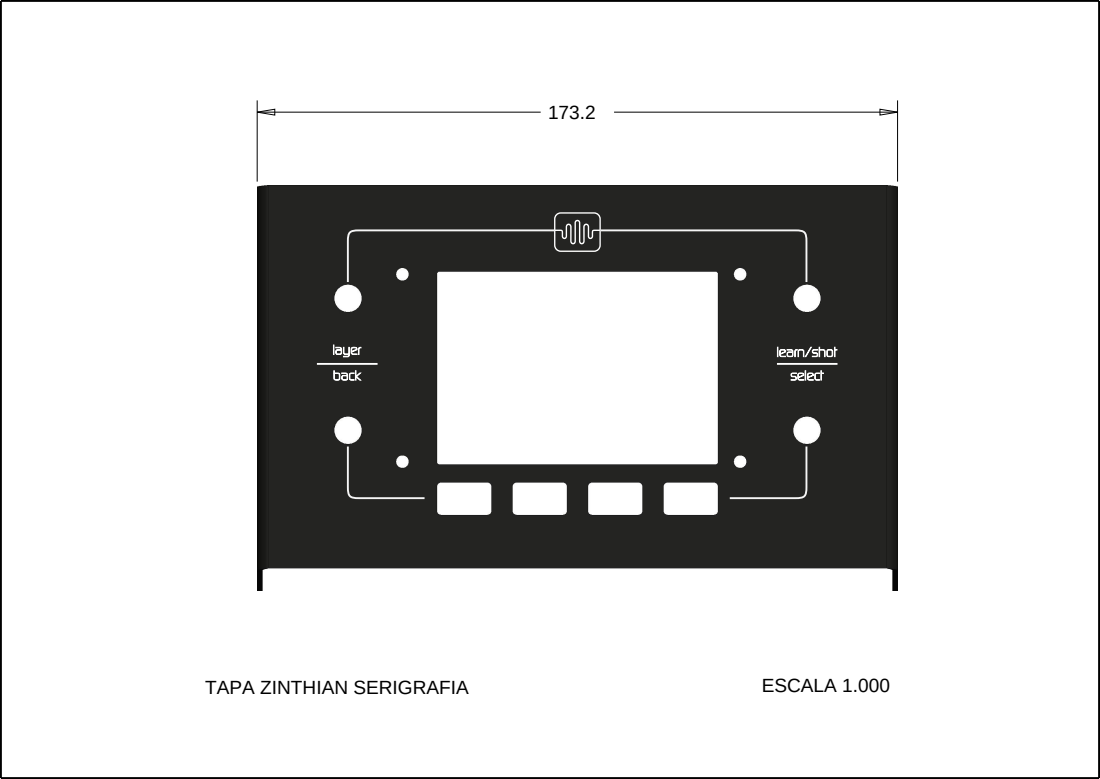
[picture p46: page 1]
TAPA ZINTHIAN SERIGRAFIA; ESCALA 1.000; layer; back; learn/shot; select

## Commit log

2016-09-21 + Initial commit
    [PaulFaldutoBox-CNC-rev.1.dxf, moog_style_knob.stl, zyn_box_down.stl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]
2016-09-21 + Add sketchup source files
    [zyn_box_down.skp, zyn_box_up.skp]
2016-10-03 + Improvements from Belén
    [zyn_box_down.skp, zyn_box_down.stl, zyn_box_up.skp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]
2017-03-06 Rename laser-cutter directory + Add some photos to the aluminum case directory.
    [zynthian_box_lasser_cutter_all.dxf, zynthian_box_lasser_cutter_partial1.dxf, zynthian_box_lasser_cutter_partial2.dxf]
2017-03-06 Minor adjustments. Increase screen window.
    [zynthian_box_lasser_cutter_all.dxf, zynthian_box_lasser_cutter_partial1.dxf, zynthian_box_lasser_cutter_partial2.dxf]
2017-03-06 Add aluminum case plots
2017-04-03 Another 3D printable case for Zynthian
    [Bottom Back.stl, Bottom Front.stl, Button.stl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]
2017-04-04 Add lasser cut design for audioinjector sound card.
    [zynthian_box_lasser_back.dxf, zynthian_box_lasser_cutter_all.dxf, zynthian_box_lasser_cutter_partial1.dxf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]
2017-05-02 Add "slope" version for laser-cutter
    [slopes.dxf, zynthian_box_lasser_cutter_all.dxf]
2017-09-29 Re-organize directories.
    [MIDI-hole.dxf, MIDI-hole2.dxf, slopes.dxf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]
2017-12-11 Fix MIDI connector orientation & adjust scale in DXF files.
    [zynthian_box_audioinjector.dxf, zynthian_box_hifiberry.dxf]
2018-02-07 Add 3D printed case for Zynthian V2.
    [bottom-box.stl, top-box.stl]
2018-04-20 Printed case Zynthian V2 - 3midi/encoderknob
    [encoderknob.FCStd, encoderknob_3mm.stl, encoderknob_4mm.stl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]
2019-09-04 + Add 3D models for RBPi4 & Hifiberry. + Add briefcase foam models. + Reorganize some dirs, etc.
    [2.54 mm DUPONT MALE PIN HEADER, IO, 2X20, RPi4ModelB.SLDPRT, 2.54 mm DUPONT MALE PIN HEADER, IO, 2X40, RPi4ModelB.SLDPRT, 2.54 mm DUPONT MALE PIN HEADER, POE, 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]
2019-09-04 Rename directory.
    [PaulFaldutoBox-CNC-rev.1.dxf]
2019-10-18 Initial commit
    Laser cut knob files added.
    [Knob.dxf]
2019-10-18 initial commit
    Added laser-cut knobs with files and instructions
    [knob.dxf]
2019-10-18 Knob.dxf deleted
    [Knob.dxf]
2020-01-10 Add Andrei Demidenko's Custom RBPi4+Zynscreen case
    [Pi4_case_back.dxf, Pi4_case_bottom_v2.dxf, Pi4_case_face.dxf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]
2020-01-10 Add 3D model (step) for HifiBerry DAC+ADC PRO.
2020-01-10 Rename dir.
    [Pi4_case_back.dxf, Pi4_case_bottom_v2.dxf, Pi4_case_face.dxf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]
2020-05-08 Added 3D printed case files
2020-08-05 Add Aluminum Case v4 files + Suitcase files
    [ZYNT1.IGS, ZYNT2.IGS, ZYNT3.IGS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]
2021-02-05 Zynscreen 1.5 and HiFiBerry DAC+ADC
    Top and back plates redesigned to fit Zynscreen and HiFiBerry.
    [Zynthian case back RPI4 HFB DAC+ADC.f3d, Zynthian case back RPI4 HFB DAC+ADC.stl, Zynthian case top v4.stl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]
2023-01-17 Create Lanfranco 3D Print
2023-01-18 3D Case Zynthian
2023-01-30 Add files via upload
    Zynthian case 3D printing
    [Copri SD.stl, Fianco DX.stl, Fianco SX.stl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]
2023-01-31 Add files via upload
    All printed in PETG or ABS, the two sides are glued to the bottom, the rest is fixed with inserts and screws and interlocking.
    [Copri SD.stl, Fianco DX.stl, Fianco SX.stl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]
2023-07-19 Add V5 aluminum case files.
    [Zynthian_V5_BENDED_BOTTOM-230313.stp, Zynthian_V5_BENDED_CASE-230313.stp, Zynthian_V5_BENDED_TOP-230313.stp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]
2023-07-19 + Add design files for the silicone buttons. + Add some pictures from the aluminum case.
2024-05-05 added MINI V2 3d printable case
    [Raspberry_Pi_4_B.STEP, bottom.stl, leg.stl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]
2024-05-10 adjusted case to MIN V2 PCB rev2
2024-05-13 added screws and posts to case
    [zynthian-mini-PCB-v2-facia.step]
2024-05-13 added display and encoder caps
2024-05-13 changed directory name for MINI_V2
    [Raspberry_Pi_4_B.STEP, bottom.stl, leg.stl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]
2025-04-28 Improve file names.
    [2.54 mm DUPONT MALE PIN HEADER, IO, 2X20, RPi4ModelB.SLDPRT, 2.54 mm DUPONT MALE PIN HEADER, IO, 2X40, RPi4ModelB.SLDPRT, 2.54 mm DUPONT MALE PIN HEADER, POE, 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]
